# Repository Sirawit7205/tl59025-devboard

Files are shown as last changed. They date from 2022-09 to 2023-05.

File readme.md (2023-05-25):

# TLC59025 Devboard

This is an open-source KiCAD design files for a development for [Texas Instruments TLC59025](https://www.ti.com/lit/ds/symlink/tlc59025.pdf) 16-Channel Constant Current LED Driver (and clones).

## Pictures

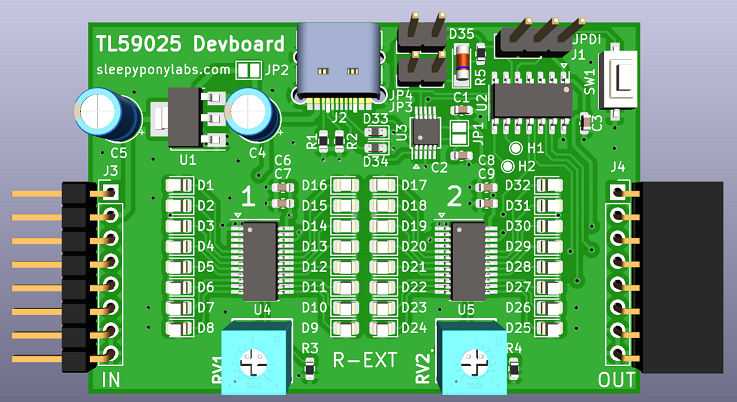
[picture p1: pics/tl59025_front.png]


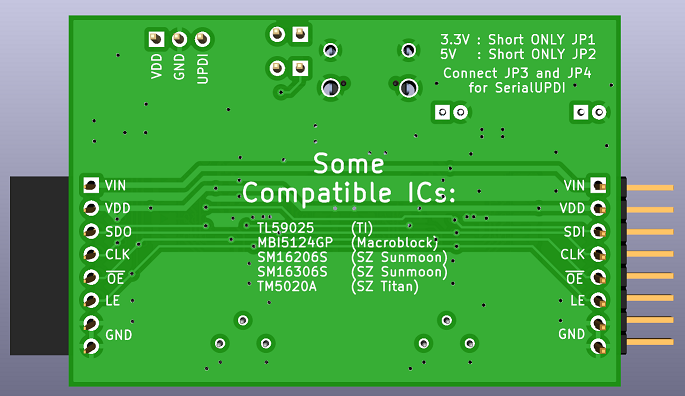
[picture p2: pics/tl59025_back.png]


## Features

This devboard provides full flexibility for testing various configurations of the chip and surrounding circuits.

- Support original and clones in QSOP-24 package:
	- TI TLC59025IDBQR
	- Macroblock MBI5124GP
	- Shenzhen Sunmoon SM16206S
	- Shenzhen Sunmoon SM16306S
	- Shenzhen Titan TM5020A
- Full control over the chip's functions:
	- Output LEDs on all output channels.
	- R-EXT trimpot on each chip for adjusting the sink current.
	- All control pins break out.
- Cascade design
	- Input and output headers provided for cascading of modules (allows single controller only).
- Multiple power options
	- USB Type-C
	- Input header (both regulated and unregulated)
	- Optional footprint for an LDO.
- Onboard Microcontroller
	- Optional footprint for ATtiny214/414/814.
	- A user button and several debug pads provided.
	- A CH340 bridge for serial communication with a computer.
	- UPDI Header included.
	- SerialUPDI support included.
	
## Revisions

We are currently at Revision 1. Changelog is below:

**Revision 1 (September 2022)**
 - Initial Design

## What is provided

The goal of this repository is to enable you to build this on your own as easy as possible (although I originally plan to sell this as a kit as well). **The schematics, PCB design, and an interactive BOM is provided.**

Hardware is licensed under `SPDX-License-Identifier: CERN-OHL-S-2.0`

Software is licensed under `SPDX-License-Identifier: GPL` (Actually there is no software for this board. Oops.)

Documentation is licensed under `SPDX-License-Identifier: CC-BY-SA-4.0`

**This project is an OSHWA Certified Open Source Hardware Project with UID [TH000010](https://certification.oshwa.org/th000010.html).**

3D models that are use to render the board in KiCAD is not included. They are all from GrabCad and you could search and download them by yourself.

## Third-Party 3D Models

- 6x3.5mm Tactile Button by Gabriel Tóth: https://grabcad.com/library/6x3-5mm-smd-tactile-button-1
- Bourns 3362P Trimpot by Markus Walter: https://grabcad.com/library/bourns-3362p-1-102lf
- USB Type-C port by Hamza Huzair: https://grabcad.com/library/usb-type-c-port-smd-type-1
 
 ## Ordering
 
 You can export gerbers from this project and order the board yourself. You can also use the link below to directly order from Aisler.
 https://aisler.net/p/IMLSHTDQ

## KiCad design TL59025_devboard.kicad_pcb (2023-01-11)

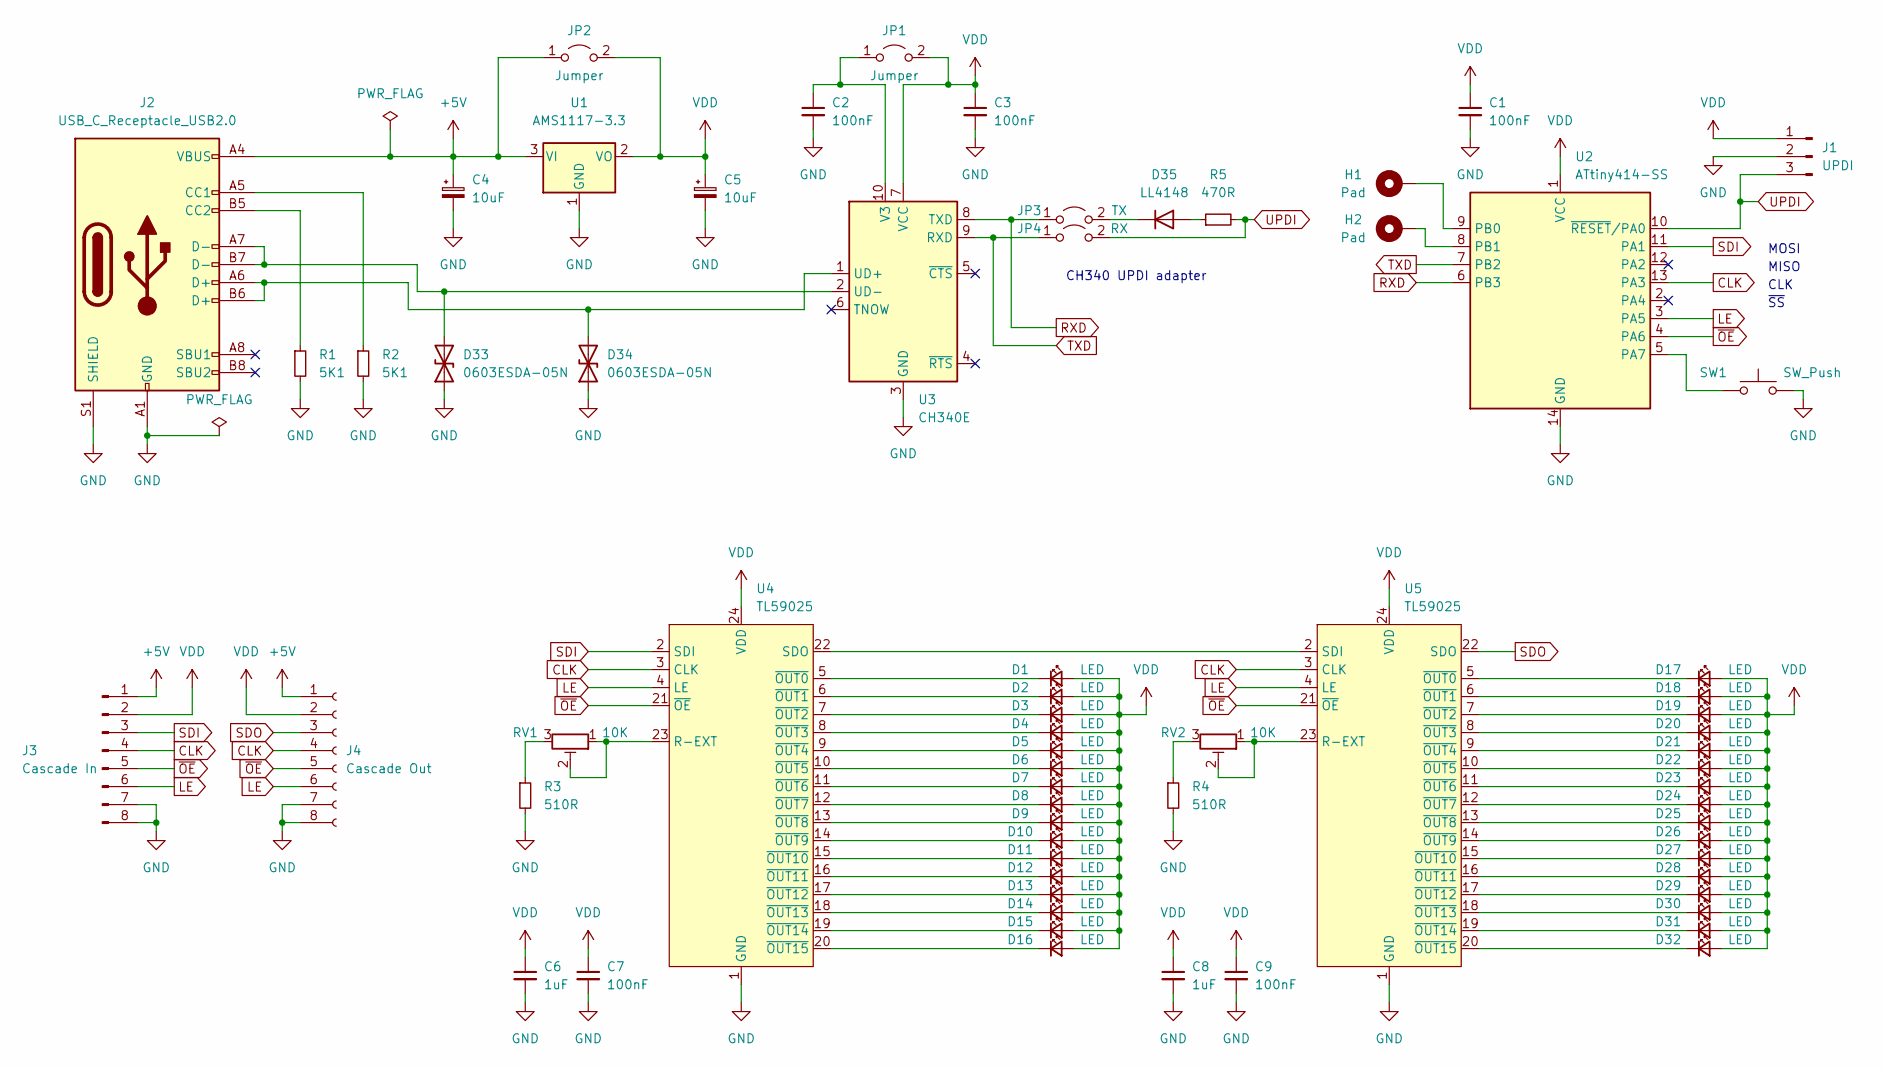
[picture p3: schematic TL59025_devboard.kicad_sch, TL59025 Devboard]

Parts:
C1, C2, C3, C7, C9: 100nF; C_0603_1608Metric
C4, C5: 10uF; CP_Radial_D5.0mm_P2.00mm
C6, C8: 1uF; C_0603_1608Metric
D1, D2, D3, D4, D5, D6, D7, D8, D9, D10, D11, D12, D13, D14, D15, D16, D17, D18, D19, D20, D21, D22, D23, D24, D25, D26, D27, D28, D29, D30, D31, D32: LED; LED_0805_2012Metric
D33, D34: 0603ESDA-05N; D_0603_1608Metric
D35: LL4148; D_MiniMELF
H1, H2: Pad; TestPoint_Pad_D1.0mm
J1: UPDI; PinHeader_1x03_P2.54mm_Vertical
J2: USB_C_Receptacle_USB2.0; USB_C_Receptacle_HRO_TYPE-C-31-M-12_NO_SBU_CircularHoles
J3: Cascade In; PinHeader_1x08_P2.54mm_Vertical
J4: Cascade Out; PinSocket_1x08_P2.54mm_Vertical
JP1, JP2: Jumper; SolderJumper-2_P1.3mm_Open_Pad1.0x1.5mm
JP3: TX; PinHeader_1x02_P2.54mm_Vertical
JP4: RX; PinHeader_1x02_P2.54mm_Vertical
R1, R2: 5K1; R_0603_1608Metric
R3, R4: 510R; R_0603_1608Metric
R5: 470R; R_0603_1608Metric
RV1, RV2: 10K; 3362P_1
SW1: SW_Push; TS-1101
U1: AMS1117-3.3; SOT-223-3_TabPin2
U2: ATtiny414-SS; SOIC-14_3.9x8.7mm_P1.27mm
U3: CH340E; MSOP-10_3x3mm_P0.5mm
U4, U5: TL59025; QSOP-24_3.9x8.7mm_P0.635mm

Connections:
+5V: C4.1, J2.A4 (VBUS), J2.A9 (VBUS), J2.B4 (VBUS), J2.B9 (VBUS), J3.1, J4.1, JP2.1 (A), U1.3 (VI)
CLK: J3.4, J4.4, U2.13 (PA3), U4.3 (CLK), U5.3 (CLK)
GND: C1.2, C2.2, C3.2, C4.2, C5.2, C6.2, C7.2, C8.2, C9.2, D33.1 (A1), D34.1 (A1), J1.2, J2.A1 (GND), J2.A12 (GND), J2.B1 (GND), J2.B12 (GND), J2.S1 (SHIELD), J3.7, J3.8, J4.7, J4.8, R1.2, R2.2, R3.2, R4.2, SW1.2, U1.1 (GND), U2.14 (GND), U3.3 (GND), U4.1 (GND), U5.1 (GND)
LE: J3.6, J4.6, U2.3 (PA5), U4.4 (LE), U5.4 (LE)
unnamed: C2.1, JP1.1 (A), U3.10 (V3)
unnamed: D1.1 (K), U4.5 (~OUT0)
unnamed: D2.1 (K), U4.6 (~OUT1)
unnamed: D3.1 (K), U4.7 (~OUT2)
unnamed: D4.1 (K), U4.8 (~OUT3)
unnamed: D5.1 (K), U4.9 (~OUT4)
unnamed: D6.1 (K), U4.10 (~OUT5)
unnamed: D7.1 (K), U4.11 (~OUT6)
unnamed: D8.1 (K), U4.12 (~OUT7)
unnamed: D9.1 (K), U4.13 (~OUT8)
unnamed: D10.1 (K), U4.14 (~OUT9)
unnamed: D11.1 (K), U4.15 (~OUT10)
unnamed: D12.1 (K), U4.16 (~OUT11)
unnamed: D13.1 (K), U4.17 (~OUT12)
unnamed: D14.1 (K), U4.18 (~OUT13)
unnamed: D15.1 (K), U4.19 (~OUT14)
unnamed: D16.1 (K), U4.20 (~OUT15)
unnamed: D17.1 (K), U5.5 (~OUT0)
unnamed: D18.1 (K), U5.6 (~OUT1)
unnamed: D19.1 (K), U5.7 (~OUT2)
unnamed: D20.1 (K), U5.8 (~OUT3)
unnamed: D21.1 (K), U5.9 (~OUT4)
unnamed: D22.1 (K), U5.10 (~OUT5)
unnamed: D23.1 (K), U5.11 (~OUT6)
unnamed: D24.1 (K), U5.12 (~OUT7)
unnamed: D25.1 (K), U5.13 (~OUT8)
unnamed: D26.1 (K), U5.14 (~OUT9)
unnamed: D27.1 (K), U5.15 (~OUT10)
unnamed: D28.1 (K), U5.16 (~OUT11)
unnamed: D29.1 (K), U5.17 (~OUT12)
unnamed: D30.1 (K), U5.18 (~OUT13)
unnamed: D31.1 (K), U5.19 (~OUT14)
unnamed: D32.1 (K), U5.20 (~OUT15)
unnamed: D33.2 (A2), J2.A7 (D-), J2.B7 (D-), U3.2 (UD-)
unnamed: D34.2 (A2), J2.A6 (D+), J2.B6 (D+), U3.1 (UD+)
unnamed: D35.1 (K), JP3.2 (B)
unnamed: D35.2 (A), R5.1
unnamed: H1.1, U2.9 (PB0)
unnamed: H2.1, U2.8 (PB1)
unnamed: J2.A5 (CC1), R2.1
unnamed: J2.B5 (CC2), R1.1
unnamed: R3.1, RV1.3
unnamed: R4.1, RV2.3
unnamed: RV1.1, RV1.2, U4.23 (R-EXT)
unnamed: RV2.1, RV2.2, U5.23 (R-EXT)
unnamed: SW1.1, U2.5 (PA7)
unnamed: U4.22 (SDO), U5.2 (SDI)
RXD: JP3.1 (A), U2.6 (PB3), U3.8 (TXD)
SDI: J3.3, U2.11 (PA1), U4.2 (SDI)
SDO: J4.3, U5.22 (SDO)
TXD: JP4.1 (A), U2.7 (PB2), U3.9 (RXD)
UPDI: J1.3, JP4.2 (B), R5.2, U2.10 (~RESET/PA0)
VDD: C1.1, C3.1, C5.1, C6.1, C7.1, C8.1, C9.1, D1.2 (A), D2.2 (A), D3.2 (A), D4.2 (A), D5.2 (A), D6.2 (A), D7.2 (A), D8.2 (A), D9.2 (A), D10.2 (A), D11.2 (A), D12.2 (A), D13.2 (A), D14.2 (A), D15.2 (A), D16.2 (A), D17.2 (A), D18.2 (A), D19.2 (A), D20.2 (A), D21.2 (A), D22.2 (A), D23.2 (A), D24.2 (A), D25.2 (A), D26.2 (A), D27.2 (A), D28.2 (A), D29.2 (A), D30.2 (A), D31.2 (A), D32.2 (A), J1.1, J3.2, J4.2, JP1.2 (B), JP2.2 (B), U1.2 (VO), U2.1 (VCC), U3.7 (VCC), U4.24 (VDD), U5.24 (VDD)
~OE: J3.5, J4.5, U2.4 (PA6), U4.21 (~OE), U5.21 (~OE)

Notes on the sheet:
~{SS}
CH340 UPDI adapter
CLK
MISO
MOSI

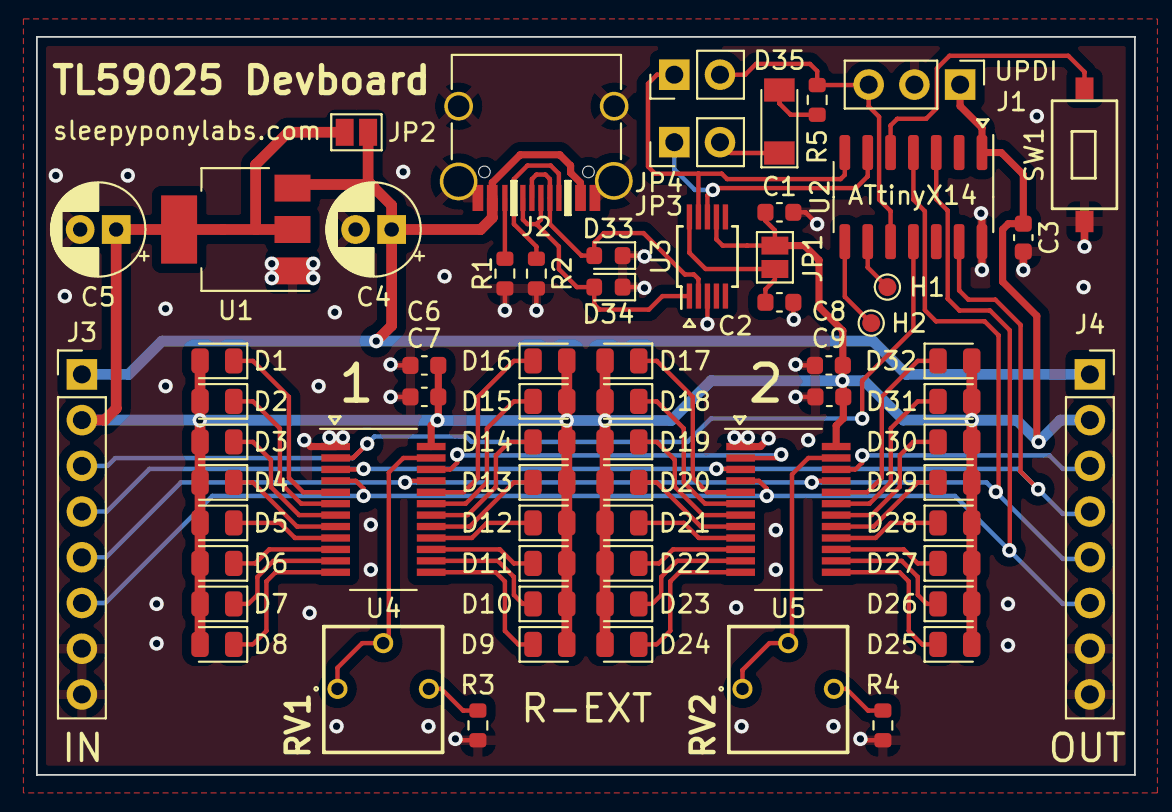
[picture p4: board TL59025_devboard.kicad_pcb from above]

Board: 2 copper layers, 61.0 x 41.0 mm, 67 parts (0 on the bottom side), 58 nets.

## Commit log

2022-09-18 Add IBOM and render images
    [TL59025_devboard.kicad_pcb, TL59025_devboard.kicad_sch]
2023-01-11 Change R3 and R4 to 510R for maximum current range
    [TL59025_devboard.kicad_pcb, TL59025_devboard.kicad_sch]
